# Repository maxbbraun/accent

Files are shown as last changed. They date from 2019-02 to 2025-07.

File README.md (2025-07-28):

# Accent

Accent is a smart picture frame with a pop of color and no cables. Read more about it [on Medium](https://accent.ink/info).

Accent (https://accent.ink)

## Client

The Accent client uses the [PlatformIO Arduino toolchain](https://platformio.org) for the [Waveshare ESP32 board](https://www.waveshare.com/wiki/E-Paper_ESP32_Driver_Board). See the [client control flow](client/README.md) for a high-level overview of the client code.

To push the client code to the board:
1. Configure the [IDE](https://platformio.org/platformio-ide) or [CLI](https://platformio.org/install/cli) with [`platformio.ini`](client/platformio.ini).
2. Pick one display type via `build_flags` in [`platformio.ini`](client/platformio.ini):
   - [GDEW075Z09](https://www.e-paper-display.com/products_detail/productId=324.html)  (7.5" 640x384 3-color)
   - [GDEW075Z08](https://www.e-paper-display.com/products_detail/productId=457.html) (7.5" 800x480 3-color)
   - [GDEH075Z90](https://www.good-display.com/product/344.html) (7.5" 880x528 3-color)
   - [GDEY1248Z51](https://www.good-display.com/product/422.html) (12.48" 1304x984 3-color, requires [DESPI-C1248](https://www.e-paper-display.com/products_detail/productId=418.html) adapter)
   - [GDEY073D46](https://www.good-display.com/product/442.html) (7.3" 800x480 7-color, comes with DESPI-C73 adapter)
3. If you want to point the client to a custom server, change `kBaseUrl` in [`Client.cpp`](client/src/Client.cpp).
4. Compile and upload with `pio run -t upload`.

Follow the on-screen instructions to connect the client to a Wifi access point. The settings will be preserved across uploads and can be reset manually. See the [setup documentation](https://accent.ink/setup) for details.

## Server

The Accent server is built on [Google App Engine](https://cloud.google.com/appengine/) using the [Python 3 runtime in the standard environment](https://cloud.google.com/appengine/docs/standard/python3/runtime). See the [server control flow](server/README.md) for a high-level overview of the server code.

The database backend uses [Cloud Firestore](https://firebase.google.com/products/firestore/). User-specific data is stored in the `users` collection with each user identified by a key generated by the client to identify it.
   - `/users/<USER_KEY>/home` - The home address used for the local time, the weather, and the commute origin.
   - `/users/<USER_KEY>/work` - The work address used for the commute destination.
   - `/users/<USER_KEY>/travel_mode` - The commute [travel mode](https://developers.google.com/maps/documentation/directions/intro#TravelModes).
   - `/users/<USER_KEY>/rotation` - The display rotation in degrees (0, 90, 180, or 270).
   - `/users/<USER_KEY>/schedule` - The content schedule.
   - `/users/<USER_KEY>/google_calendar_credentials` - The OAuth credentials for Google Calendar.

To populate the cross-user data after [setting up](https://firebase.google.com/docs/firestore/quickstart):
1. Obtain an API key for [Google Maps](https://cloud.google.com/maps-platform) and add it the `api_keys` collection under `/api_keys/google_maps/api_key`. Ensure that the [Maps Static API](https://console.cloud.google.com/apis/library/static-maps-backend.googleapis.com), [Directions API](https://console.cloud.google.com/apis/library/directions-backend.googleapis.com), [Geocoding API](https://console.cloud.google.com/apis/library/geocoding-backend.googleapis.com), [Maps Elevation API](https://console.cloud.google.com/apis/library/elevation-backend.googleapis.com), and [Time Zone API](https://console.cloud.google.com/apis/library/timezone-backend.googleapis.com) are all enabled and added to the key's restrictions. The [Cloud Vision API](https://console.cloud.google.com/apis/library/vision.googleapis.com) and [Google Calendar API](https://console.cloud.google.com/apis/library/calendar-json.googleapis.com) also need to be enabled, but they do not need a key.
2. Obtain an API key for [OpenWeather](https://openweathermap.org/guide) and add it in the `api_keys` collection under `/api_keys/open_weather/api_key`.
3. Obtain an [OAuth client ID](https://console.developers.google.com/apis/credentials) for the [Google Calendar API](https://developers.google.com/calendar/quickstart/python) with scope `https://www.googleapis.com/auth/calendar.readonly` in the OAuth consent screen. You will either need to make your OAuth app public or add your account to the list of test users. Configure the full `/oauth` URL of your App Engine app as an authorized redirect URI for the OAuth client. Write OAuth Client ID and Client Secret to the `client_id` and `client_secret` fields of the `google_calendar` document in the `oauth_clients` Firestore collection (`/oauth_clients/google_calendar`).

To test and deploy the server:
1. Install the [Google Cloud SDK](https://cloud.google.com/sdk/docs/), [create a project](https://cloud.google.com/resource-manager/docs/creating-managing-projects), and [authenticate with a service account](https://cloud.google.com/docs/authentication/getting-started).
2. Run `cd server && python3 -m venv venv && . venv/bin/activate`.
3. Run `pip install -r requirements.txt` (which also builds the [C extension](server/dithering_extension)).
4. Run the server locally with `export GOOGLE_CLOUD_PROJECT=$(gcloud config get-value project) && python main.py`.
5. Test the local server with:
   - [/hello/<USER_KEY>](http://localhost:8080/hello/<USER_KEY>) for the settings UI to edit user-specific data.
   - [/next?key=<USER_KEY>](http://localhost:8080/next?key=<USER_KEY>) for the time in milliseconds until the next schedule entry.
   - [/epd?key=<USER_KEY>](http://localhost:8080/epd?key=<USER_KEY>) for the currently scheduled client image used by the e-paper display.
   - [/gif?key=<USER_KEY>](http://localhost:8080/gif?key=<USER_KEY>) for a GIF version of the currently scheduled image for testing.
   - [/aicon?key=<USER_KEY>](http://localhost:8080/aicon?key=<USER_KEY>) to bypass the schedule and get the aicon image directly.
   - [/artwork?key=<USER_KEY>](http://localhost:8080/artwork?key=<USER_KEY>) to bypass the schedule and get the artwork image directly.
   - [/city?key=<USER_KEY>](http://localhost:8080/city?key=<USER_KEY>) to bypass the schedule and get the city image directly.
   - [/commute?key=<USER_KEY>](http://localhost:8080/commute?key=<USER_KEY>) to bypass the schedule and get the commute image directly.
   - [/calendar?key=<USER_KEY>](http://localhost:8080/calendar?key=<USER_KEY>) to bypass the schedule and get the calendar image directly.
   - [/everyone?key=<USER_KEY>](http://localhost:8080/everyone?key=<USER_KEY>) to bypass the schedule and get the everyone image directly.
   - [/wittgenstein?key=<USER_KEY>](http://localhost:8080/wittgenstein?key=<USER_KEY>) to bypass the schedule and get the wittgenstein image directly.
6. Deploy the server with `gcloud app deploy`.

## Frame

Files describing the Accent frame hardware include:
- A [Blender](https://www.blender.org/) project for simulating materials: [`frame.blend`](frame/frame.blend)
- A blueprint with basic dimensions: [`frame.pdf`](frame/frame.pdf)
- A [Shaper Origin](https://www.shapertools.com/) design: [`frame.svg`](frame/frame.svg)
- A [FreeCAD](https://www.freecadweb.org/) project: [`frame.FCStd`](frame/frame.FCStd)
- A G-code file for CNC milling: [`frame.gcode`](frame/frame.gcode)
- 3D models in STEP and STL formats: [`frame.step`](frame/frame.step) & [`frame.stl`](frame/frame.stl)

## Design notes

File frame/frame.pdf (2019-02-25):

1.00 mm

9.98 mm

3.02 mm

35.00 mm | 67.60 mm

123.63 mm

189.45 mm

170.20 mm

111.20 mm

97.63 mm

163.45 mm

3.38 mm

9.62 mm

1.00 mm

12.70 mm

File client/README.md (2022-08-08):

## Client

Entry point: [`Client.cpp`](src/Client.cpp)

### Regular Flow

```
┌────────────┐       ┌────────────┐       ┌────────────┐
│   Server   │       │   ESP32    │       │  Display   │
└─────┬──────┘       └─────┬──────┘       └─────┬──────┘
      │                    │                    │
      │                    ├───┐                │
      │                    │   │ Wake           │
      │                    │◀──┘                │
      │                    │                    │
      │                    ├───┐                │
      │                    │   │ Connect Wifi   │
      │                    │◀──┘                │
      │  /epd (Key, Size)  │                    │
    ┌─┤◀───────────────────┤                    │
    │ │                    │                    │
    │ │       Image        │                    │
    └─┼ ─ ─ ─ ─ ─ ─ ─ ─ ─ ▷│                    │
      │                    │    Show (Image)    │
      │                    ├───────────────────▶├─┐
      │                    │                    │ │
      │                    │                    │ │
      │                    │◁ ─ ─ ─ ─ ─ ─ ─ ─ ─ ┼─┘
      │    /next (Key)     │                    │
    ┌─┤◀───────────────────┤                    │
    │ │                    │                    │
    │ │     Sleep Time     │                    │
    └─┼ ─ ─ ─ ─ ─ ─ ─ ─ ─ ▷│                    │
      │                    │                    │
      │                    ├───┐                │
      │                    │   │ Sleep          │
      │                    │◀──┘                │
      │                    │                    │

```

### New Wifi Flow

```
┌────────────┐       ┌────────────┐       ┌────────────┐
│  Browser   │       │   ESP32    │       │  Display   │
└─────┬──────┘       └─────┬──────┘       └─────┬──────┘
      │                    │                    │
      │                    ├───┐                │
      │                    │   │ Wake           │
      │                    │◀──┘                │
      │                    │                    │
      │                    ├───┐                │
      │                    │   │ Connect Wifi   │
      │                    │x──┘                │
      │                    │                    │
      │                    │   Show (AP URL)    │
      │                    ├───────────────────▶├─┐
      │                    │                    │ │
      │                    │                    │ │
      │                    │◁ ─ ─ ─ ─ ─ ─ ─ ─ ─ ┼─┘
      │                    │                    │
      │                    ├───┐                │
      │                    │   │ Start AP       │
      │  AP URL            │◀──┘                │
    ┌─┤◀────────○          │                    │
    │ │                    │                    │
    │ │  Wifi Credentials  │                    │
    └─┤─ ─ ─ ─ ─ ─ ─ ─ ─ ─▷│                    │
      │                    │                    │
      │                    ├───┐                │
      │                    │   │ Restart        │
      │                    │◀──┘                │
      │                    │                    │
   ┌──┴────────────────────┴────────────────────┴──┐
   │                                               │
   │                 Regular Flow                  │
   │                                               │
   └──┬────────────────────┬────────────────────┬──┘
      │                    │                    │
```

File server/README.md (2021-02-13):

## Server

Entry point: [`main.py`](main.py)

### Regular Flow

```
┌────────────┐       ┌────────────┐       ┌────────────┐
│   Client   │       │ App Engine │       │ Firestore  │
└─────┬──────┘       └─────┬──────┘       └─────┬──────┘
      │                    │                    │
      ├───┐                │                    │
      │   │ Wake           │                    │
      │◀──┘                │                    │
      │                    │                    │
      │  /epd (Key, Size)  │                    │
      ├───────────────────▶├─┐ Schedule (User)  │
      │                    │ ├─────────────────▶├─┐
      │                    │ │                  │ │
      │                    │ │    User Data     │ │
      │   Content Image    │ │◁ ─ ─ ─ ─ ─ ─ ─ ─ ┼─┘
      │◁ ─ ─ ─ ─ ─ ─ ─ ─ ─ ┼─┘                  │
      │                    │                    │
      ├───┐                │                    │
      │   │ Display        │                    │
      │◀──┘                │                    │
      │                    │                    │
      │    /next (Key)     │                    │
      ├───────────────────▶├─┐ Schedule (User)  │
      │                    │ ├─────────────────▶├─┐
      │                    │ │                  │ │
      │                    │ │    User Data     │ │
      │     Sleep Time     │ │◁ ─ ─ ─ ─ ─ ─ ─ ─ ┼─┘
      │◁ ─ ─ ─ ─ ─ ─ ─ ─ ─ ┼─┘                  │
      │                    │                    │
      ├───┐                │                    │
      │   │ Sleep          │                    │
      │◀──┘                │                    │
      │                    │                    │
```

### New User Flow

```
┌────────────┐       ┌────────────┐       ┌────────────┐       ┌────────────┐
│   Client   │       │ App Engine │       │ Firestore  │       │  Browser   │
└─────┬──────┘       └─────┬──────┘       └─────┬──────┘       └─────┬──────┘
      │                    │                    │                    │
      ├───┐                │                    │                    │
      │   │ Wake           │                    │                    │
      │◀──┘                │                    │                    │
      │                    │                    │                    │
      │  /epd (Key, Size)  ├─┐ Schedule (User)  │                    │
      ├───────────────────▶│ ├─────────────────▶├─┐                  │
      │                    │ │                  │ │                  │
      │                    │ │      Error       │ │                  │
      │ Settings URL Image │ │x ─ ─ ─ ─ ─ ─ ─ ─ ┼─┘                  │
      │◁ ─ ─ ─ ─ ─ ─ ─ ─ ─ ┼─┘                  │                    │
      │                    │                    │                    │
      ├───┐                │                    │                    │
      │   │ Display        │                    │                    │
      │◀──┘                │                    │       Settings URL │
      │                    │                    │     ○─────────────▶├─┐
      ├───┐                │                    │                    │ │
      │   │ Sleep          │                    │     User Data      │ │
      │◀──┘                │                    │◁ ─ ─ ─ ─ ─ ─ ─ ─ ─ ┼─┘
      │                    │                    │                    │
   ┌──┴────────────────────┴────────────────────┴────────────────────┴──┐
   │                                                                    │
   │                            Regular Flow                            │
   │                                                                    │
   └──┬────────────────────┬────────────────────┬────────────────────┬──┘
      │                    │                    │                    │
```

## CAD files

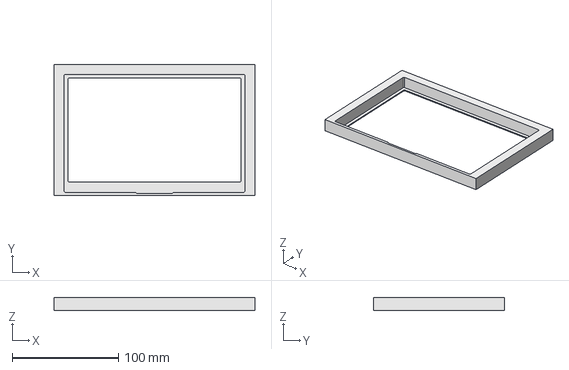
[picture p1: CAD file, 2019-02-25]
frame/frame.step
189.4 x 123.6 x 12.7 mm

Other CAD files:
frame/frame.FCStd
frame/frame.blend
frame/frame.stl

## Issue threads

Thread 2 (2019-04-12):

Red color and voltage

maxbbraun, 2019-04-12:
Sometimes, when using 3.7V battery power, the red pixels are not bright enough. This does not happen with 5V USB power.

There may be a different way to [initialize](https://github.com/maxbbraun/accent/blob/master/client/display.h#L89) or [refresh](https://github.com/maxbbraun/accent/blob/master/client/display.h#L158) the display which avoids this issue.

maxbbraun, 2021-02-16:
9868d1da35801458c72f2fb4c08cf8ae0a589f81 and using the [GDEW075Z08](https://www.e-paper-display.com/products_detail/productId=457.html) (800x480) display seems to fix this.

Closed 2021-02-16.

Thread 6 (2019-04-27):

Client interface for Wifi setup

maxbbraun, 2019-04-27:
1. At first boot, create an [access point](https://github.com/espressif/arduino-esp32/blob/master/libraries/WiFi/examples/WiFiAccessPoint/WiFiAccessPoint.ino) with a [static IP](https://github.com/espressif/arduino-esp32/blob/master/libraries/WiFi/src/WiFiAP.cpp#L147)
2. Show an image with instructions to connect to the AP and open a browser to the IP address
3. [Serve](https://github.com/espressif/arduino-esp32/blob/master/libraries/WebServer/examples/HelloServer/HelloServer.ino) a small website with a form for SSID and password
4. Handle the form request by saving SSID and password to [NVS](https://docs.espressif.com/projects/esp-idf/en/latest/api-reference/storage/nvs_flash.html)
5. Use the saved credentials when [connecting to Wifi](https://github.com/maxbbraun/accent/blob/master/client/client.ino#L61)
6. If connecting to Wifi fails or times out, go back to 1

maxbbraun, 2019-05-04:
Some remaining work:
- Make web server use https
- Respond with confirmation after saving form and restarting

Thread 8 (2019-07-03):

Not all map copyright text is properly replaced

maxbbraun, 2019-07-03:
Failure case example:

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

maxbbraun, 2019-07-03:
Better:

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

Closed 2019-07-03.

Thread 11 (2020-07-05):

Dark Sky API no longer accepting signups

KianYeo, 2020-07-05:
Hi,

The Dark Sky API is no longer accepting signups. Are there any other alternatives or what modifications can be made to the server code to disable the dark sky api call?

maxbbraun, 2020-07-05:
Switched to the [AccuWeather API](https://developer.accuweather.com) in 1c4fe954a23f8fa932ececf023520b2baddb0d99.

Closed 2020-07-05.

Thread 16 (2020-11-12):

Setting Up Client

energysteward, 2020-11-12:
I'm trying to follow these instructions from your ReadMe.

To push the client code to the board:

Add your server base URL to Client.ino.
Use the board information in Client.ino to set up the environment.
Verify and upload the sketch.
Finally, follow the on-screen instructions to connect the client to a Wifi access point.

Honestly, I've never worked with Arduino devices. I followed the instructions but nothing is appearing on the e-ink screen. These are instructions are too "calm" for me.

I verified, compiled and uploaded the client.ino file with no errors, but nothing is occuring. The e-ink screen is blank white.

What am I missing?

maxbbraun, 2020-11-16:
Could you paste the serial output from the client here?

NeilBetham, 2021-04-09:
I seem to be running into a similar issue with a recent ESP32 e-Paper dev board from Waveshare. Oddly enough after flashing the board the first stage bootloader fires up but the main app fails almost immediately after that. Somewhat surprising there isn't a stack trace getting printed.

```
ets Jun  8 2016 00:22:57

rst:0x1 (POWERON_RESET),boot:0x13 (SPI_FAST_FLASH_BOOT)
configsip: 0, SPIWP:0xee
clk_drv:0x00,q_drv:0x00,d_drv:0x00,cs0_drv:0x00,hd_drv:0x00,wp_drv:0x00
mode:DIO, clock div:1
load:0x3fff0018,len:4
load:0x3fff001c,len:1216
ho 0 tail 12 room 4
load:0x40078000,len:10944
load:0x40080400,len:6388
entry 0x400806b4
\xFFNo
```

Still trying to figure out the cause. I have a logic analyzer attached to the UART of the ESP32 and it looks like after printing the `No` text it's either resetting or something is getting corrupted which cause it to start dumping garbage to the UART. You can see that the baud rate changes significantly after the `o` is sent:
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

I'll update once I know some more about what's happening.

NeilBetham, 2021-04-09:
Okay, update. It looks like there is an issue with the arduino-esp32 compatibility layer. After digging through the GX_EPD lib there is a second call to `Serial.begin` which is causing the issue. By setting the serial baud rate to 0 in the `gx_epd->init` call inside Display.h the issue is mitigated and I can now see the AccentSetup screen when the esp32 boots. Not optimal as you no longer get debug messages from the display library but will get the display lib up and running in the short term.

maxbbraun, 2021-04-09:
Hm, I'm not able to reproduce the issue. For me, the second call to `Serial.begin` works and I get messages from both the Accent code and the GxEPD library. Is this a first run thing for you or does it still happen if you set the baud rate back to normal after the device is fully set up?

NeilBetham, 2021-04-09:
So the first `Serial.begin` in Client.ino is fine; it's whenever someone calls it again that becomes the issue. For some reason it corrupts the serial interface. I can try removing that and then letting GxEPD do the init to see if that mitigates the issue or not. Out of curiosity, what core version are you running in the arduino IDE? The version I have installed is 1.0.6.

NeilBetham, 2021-04-09:
So if I let GxEPD call `Serial.begin` I can also get the debug messages from there as well. Though I do miss the couple messages that get printed from Client.ino / Network before GxEPD init's the UART. Suffice it to say I don't think this is a bug in the Accent client just an issue in the underlying arduino-esp32 layer.

maxbbraun, 2021-04-09:
Oh, I see. I'm using Arduino IDE 1.8.13 and esp32 version 1.0.2.

NeilBetham, 2021-04-09:
Okay, confirmed the issue is in the arduino-esp32 cores somewhere after 1.0.2. I downgraded to the 1.0.2 rev and I don't experience the same hanging issue as with 1.0.6. Though calling `Serial.begin` again does appear to nuke the buffers as I miss out on most of the messages that happen between startup and GxEPD init.

maxbbraun, 2021-04-09:
I was also able to reproduce with esp32>=1.0.5 while 1.0.4 still seems to work fine.

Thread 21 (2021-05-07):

Connecting a LiPo battery to Waveshare e-Paper ESP32 board

knyar, 2021-05-07:
Hi @maxbbraun, thanks a lot for sharing the details about this project. I have a hardware-related question, I hope it's OK to ask it here.

In your [medium post](https://onezero.medium.com/meet-accent-352cfa95813a) you mentined that you connected the board to a 3.7v LiPo battery. I noticed that the board only has 5v and 3.3v pins, while LiPo batteries produce 4.2v while fully charged.

Did you use a voltage regulator while connecting the battery to the 3.3v pin, or does the board work fine with the battery connected directly to the 3.3v (or 5v)? Thanks!

maxbbraun, 2021-05-08:
I directly connected it to the 3.3V pin. Not the cleanest solution, but it worked.

knyar, 2021-05-08:
Thanks! I will try connecting directly as well.

Closed 2021-05-08.

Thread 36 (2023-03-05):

Internal Server Error when setting up new device

maxbbraun, 2023-03-05:
```
 Traceback (most recent call last):
  File "/layers/google.python.pip/pip/lib/python3.9/site-packages/flask/app.py", line 2077, in wsgi_app
    response = self.full_dispatch_request()
  File "/layers/google.python.pip/pip/lib/python3.9/site-packages/flask/app.py", line 1525, in full_dispatch_request
    rv = self.handle_user_exception(e)
  File "/layers/google.python.pip/pip/lib/python3.9/site-packages/flask/app.py", line 1523, in full_dispatch_request
    rv = self.dispatch_request()
  File "/layers/google.python.pip/pip/lib/python3.9/site-packages/flask/app.py", line 1509, in dispatch_request
    return self.ensure_sync(self.view_functions[rule.endpoint])(**req.view_args)
  File "/srv/auth.py", line 90, in wrapper
    return settings_response(key, image_response, width,
  File "/srv/response.py", line 90, in settings_response
    return image_func(image)
TypeError: epd_response() missing 1 required positional argument: 'variant'
```

Closed 2023-03-05.

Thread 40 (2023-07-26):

Internal Server Error on /hello/<USER_KEY>

bdaneshgar, 2023-07-26:
I am thinking out loud. I get a server error when testing  `/hello/<USER_KEY>`

My calendar is probably set up incorrectly:
- I have only filled `oath_client/google_calendar `document with the `client_id` and `client_secret`
- I have not filled out the `/users/<USER_KEY>/google_calendar_credentials`
- Is `/users/<USER_KEY>/google_calendar_credentials` to be set up in the `/hello/<USER_KEY>` page.

Any insight into helping me get into thepage is much appreciated!

> [/hello/<USER_KEY>](http://localhost:8080/hello/%3CUSER_KEY%3E) for the settings UI to edit user-specific data.

Internal Server Error

> [/next?key=<USER_KEY>](http://localhost:8080/next?key=%3CUSER_KEY%3E) for the time in milliseconds until the next schedule entry.

This works

> [/epd?key=<USER_KEY>](http://localhost:8080/epd?key=%3CUSER_KEY%3E) for the currently scheduled client image used by the e-paper display.

This downloads serial gibberish

> [/gif?key=<USER_KEY>](http://localhost:8080/gif?key=%3CUSER_KEY%3E) for a GIF version of the currently scheduled image for testing.

this triggers the `settings_response` function in `response.py`

> [/artwork?key=<USER_KEY>](http://localhost:8080/artwork?key=%3CUSER_KEY%3E) to bypass the schedule and get the artwork image directly.

This works

> [/city?key=<USER_KEY>](http://localhost:8080/city?key=%3CUSER_KEY%3E) to bypass the schedule and get the city image directly.

This works

> [/commute?key=<USER_KEY>](http://localhost:8080/commute?key=%3CUSER_KEY%3E) to bypass the schedule and get the commute image directly.

This works

> [/calendar?key=<USER_KEY>](http://localhost:8080/calendar?key=%3CUSER_KEY%3E) to bypass the schedule and get the calendar image directly.

Internal Server Error

> [/everyone?key=<USER_KEY>](http://localhost:8080/everyone?key=%3CUSER_KEY%3E) to bypass the schedule and get the everyone image directly.

I am everyone

> [/wittgenstein?key=<USER_KEY>](http://localhost:8080/wittgenstein?key=%3CUSER_KEY%3E) to bypass the schedule and get the wittgenstein image directly.

This works.

bdaneshgar, 2023-07-26:
I did notice that my browser autocorrected to `oath_clients`. I noticed in the `README.md`, there is a reference to both `oauth_client` and `oauth_clients` and I see that only `oauth_clients` is valid.

I am still having trouble with my `/calendar?key=<USER_KEY>` and `/hello/<USER_KEY>`

bdaneshgar, 2023-07-26:
I took out extraneous URIs from my OAuth Client and it now works!

maxbbraun, 2023-07-28:
Thanks for catching the typo!

Closed 2023-07-26.

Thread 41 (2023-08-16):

Client only retrieves certain images

bdaneshgar, 2023-08-16:
Client will display pages `calendar`, `artwork`, `wittgenstein`, and `city`, but fails to show content and displays a `settings_response` for `commute` and `everyone`. Any idea how this could be happening? The server is creating the image just fine.

bdaneshgar, 2023-10-31:
I am using my own server. Here is the terminal from the client:

```Updating display
_PowerOn : 134997
Busy Timeout!
_Update_Full : 20001053
_PowerOff : 157000
Read 768 bytes (96000 total)
Download complete
Suspending display
_PowerOff : 40000
Scheduling sleep
Requesting URL: https://accent-393823.wl.r.appspot.com/next
Status code: 200
Sleep server response: 24262361
Sleeping for 24262361000 us

maxbbraun, 2023-11-02:
Do you see any error logs on the server? This client log looks fine, but it also only shows the request and response for `/next` and not for `/epd`, which should be just before it. If both are status `200`, then I'd expect the error to be server-side.

bdaneshgar, 2023-11-02:
I'm getting the following. I'm using a waveshare 7.5", 800x480 display:

```{
  "textPayload": "ERROR:root:Failed to create Schedule content: Requested a 800x480 map but got 640x480. Try this: https://developers.google.com/maps/documentation/maps-static/start#Largerimagesizes",
  "insertId": "6543d721000194d63da926f1",
  "resource": {
    "type": "gae_app",
    "labels": {
      "module_id": "default",
      "version_id": "20230726t204946",
      "zone": "us-west2-2",
      "project_id": "accent-393823"
    }
  },
  "timestamp": "2023-11-02T17:06:41.103638Z",
  "labels": {
    "clone_id": "0037d6d5d376b858968d6299719bd5842919fa4263d2ece4aa0be475e49ef2a3c70944e8a7c7ff3634e0728b8a85f50fef53971b9523afd72475b084676cf6908f"
  },
  "logName": "projects/accent-393823/logs/stderr",
  "receiveTimestamp": "2023-11-02T17:06:41.356828278Z"
}
```

```
{
  "textPayload": "Traceback (most recent call last):\n  File \"/srv/commute.py\", line 59, in image\n    image = self._google_maps.map_image(width, height, variant,\n  File \"/srv/google_maps.py\", line 154, in map_image\n    raise DataError('Requested a %dx%d map but got %dx%d. Try this: ht'\nfirestore.DataError: Requested a 800x480 map but got 640x480. Try this: https://developers.google.com/maps/documentation/maps-static/start#Largerimagesizes",
  "insertId": "6543d721000194f0f6995feb",
  "resource": {
    "type": "gae_app",
    "labels": {
      "zone": "us-west2-2",
      "version_id": "20230726t204946",
      "module_id": "default",
      "project_id": "accent-393823"
    }
  },
  "timestamp": "2023-11-02T17:06:41.103664Z",
  "severity": "ERROR",
  "labels": {
    "clone_id": "0037d6d5d376b858968d6299719bd5842919fa4263d2ece4aa0be475e49ef2a3c70944e8a7c7ff3634e0728b8a85f50fef53971b9523afd72475b084676cf6908f"
  },
  "logName": "projects/accent-393823/logs/stderr",
  "receiveTimestamp": "2023-11-02T17:06:41.356828278Z",
  "errorGroups": [
    {
      "id": "CM-fi8rVrO2PBQ"
    }
  ]
}
```

```
{
  "textPayload": "During handling of the above exception, another exception occurred:",
  "insertId": "6543d721000194f91d0612de",
  "resource": {
    "type": "gae_app",
    "labels": {
      "zone": "us-west2-2",
      "module_id": "default",
      "version_id": "20230726t204946",
      "project_id": "accent-393823"
    }
  },
  "timestamp": "2023-11-02T17:06:41.103673Z",
  "labels": {
    "clone_id": "0037d6d5d376b858968d6299719bd5842919fa4263d2ece4aa0be475e49ef2a3c70944e8a7c7ff3634e0728b8a85f50fef53971b9523afd72475b084676cf6908f"
  },
  "logName": "projects/accent-393823/logs/stderr",
  "receiveTimestamp": "2023-11-02T17:06:41.356828278Z"
}
```

```
{
  "textPayload": "Traceback (most recent call last):\n  File \"/srv/response.py\", line 96, in content_response\n    image = content.image(user, width, height, variant)\n  File \"/srv/schedule.py\", line 142, in image\n    image = self._image(latest_entry['image'], user, width, height,\n  File \"/srv/schedule.py\", line 110, in _image\n    return content.image(user, width, height, variant)\n  File \"/srv/commute.py\", line 62, in image\n    raise ContentError(e)\ncontent.ContentError: Requested a 800x480 map but got 640x480. Try this: https://developers.google.com/maps/documentation/maps-static/start#Largerimagesizes",
  "insertId": "6543d7210001950594c4c255",
  "resource": {
    "type": "gae_app",
    "labels": {
      "project_id": "accent-393823",
      "zone": "us-west2-2",
      "module_id": "default",
      "version_id": "20230726t204946"
    }
  },
  "timestamp": "2023-11-02T17:06:41.103685Z",
  "severity": "ERROR",
  "labels": {
    "clone_id": "0037d6d5d376b858968d6299719bd5842919fa4263d2ece4aa0be475e49ef2a3c70944e8a7c7ff3634e0728b8a85f50fef53971b9523afd72475b084676cf6908f"
  },
  "logName": "projects/accent-393823/logs/stderr",
  "receiveTimestamp": "2023-11-02T17:06:41.356828278Z",
  "errorGroups": [
    {
      "id": "COiBvcjWneT1kgE"
    }
  ]
}
```

maxbbraun, 2023-11-03:
The first error message explains what's going on:

> Failed to create Schedule content: Requested a 800x480 map but got 640x480. Try this: https://developers.google.com/maps/documentation/maps-static/start#Largerimagesizes

You can follow the link for more info and ways to fix it.

bdaneshgar, 2023-11-06:
Unfortunately, I got this response from Google Cloud Support:

> Hi,Unfortunately your request has been rejected by the engineering team since it is for personal use and low usage , please use the default maximum imagery size. if your usage increases you can try to apply again later.

 Additionally, `epd.py` has default display sizes set to 640x384. I am having trouble finding out how the larger sizes are being requested in the first place.

i will try to dig deeper and report back. In the meantime, if you are able to figure out how to lower the size of the request (or give me guidance as to how many requests I would need to satisfy Google), I would appreciate the help.

maxbbraun, 2023-11-07:
> Additionally, `epd.py` has default display sizes set to 640x384. I am having trouble finding out how the larger sizes are being requested in the first place.

The default values for the display size (and variant) are only used when the request doesn't specify any size. See [here](https://github.com/maxbbraun/accent/blob/e4d07de050256f6b0b3db25046bc9116bffa265d/server/response.py#L108). This is mainly a fallback for compatibility with older clients. So in your case, the client is requesting an 800x480 image. If your display is 640x384 instead, you should change the client configuration [here](https://github.com/maxbbraun/accent/blob/e4d07de050256f6b0b3db25046bc9116bffa265d/client/platformio.ini#L19).

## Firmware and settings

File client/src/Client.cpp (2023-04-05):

#include <Arduino.h>
#include "Display.h"
#include "Network.h"
#include "Power.h"

// The baud rate for the serial connection.
const uint32_t kSerialSpeed = 115200;

// The GPIO pin used to reset Wifi settings.
const uint8_t kWifiResetPin = 23;

// The base URL for server requests.
const String kBaseUrl = "https://accent.ink";

// The URL for the next wake time endpoint.
const String kNextEndpoint = kBaseUrl + "/next";

// The URL for the e-paper display image endpoint.
const String kEpdEndpoint = kBaseUrl + "/epd";

// The size in bytes of the streaming HTTP response and image buffers.
const uint32_t kStreamBufferSize = 1024;

// The time in milliseconds to wait before restarting after an error.
uint64_t kRestartDelayMs = 60 * 60 * 1000;  // 1 hour

// Helper library instances.
Display display(kSerialSpeed);
Network network(kSerialSpeed);
Power power;

// Streams the image from the server and sends it to the display in chunks.
bool downloadImage() {
  Serial.println("Downloading image");
  HTTPClient http;

  // Request the current image from the server.
  if (!network.HttpGet(&http, kEpdEndpoint,
                       {"width", String(display.Width()),
                        "height", String(display.Height()),
                        "variant", display.Variant()})) {
    return false;
  }

  // Start reading from the stream.
  uint8_t buffer[kStreamBufferSize];
  WiFiClient* stream = http.getStreamPtr();
  uint32_t total_count = 0;
  do {
    if (!http.connected()) {
      Serial.println("Connection lost");
      http.end();
      return false;
    }

    Serial.printf("%d bytes available\n", stream->available());

    // Fill the buffer.
    uint32_t count = stream->readBytes(buffer, sizeof(buffer));

    // Send the buffer to the display.
    display.Load(buffer, count, total_count);

    total_count += count;
    Serial.printf("Read %lu bytes (%lu total)\n", count, total_count);
  } while (stream->available() > 0);

  Serial.println("Download complete");
  http.end();
  return true;
}

// Sleeps for a time received from the server.
void scheduleSleep() {
  Serial.println("Scheduling sleep");
  HTTPClient http;

  // Request the next wake time from the server.
  if (!network.HttpGet(&http, kNextEndpoint)) {
    return;
  }

  // Read the sleep time from the server.
  String delay_ms_str = http.getString();
  http.end();
  Serial.printf("Sleep server response: %s\n", delay_ms_str.c_str());
  uint64_t delay_ms = strtoull(delay_ms_str.c_str(), nullptr, 10);
  power.DeepSleep(delay_ms);
}

void setup() {
  Serial.begin(kSerialSpeed);

  // Check if the Wifi reset pin has been connected to GND.
  pinMode(kWifiResetPin, INPUT_PULLUP);
  delay(1);  // Wait for pull-up to become active.
  if (digitalRead(kWifiResetPin) == LOW) {
    network.ResetWifi();
  }

  // Connect to Wifi or start the setup flow.
  if (!network.ConnectWifi()) {
    display.ShowWifiSetup();
    network.StartWifiSetupServer();
    return;
  }

  // Show the latest image.
  display.Initialize();
  if (!downloadImage()) {
    return;
  }
  display.Finalize();

  // Go to sleep until the next refresh.
  scheduleSleep();
}

void loop() {
  if (network.HandleWifiSetupServer()) {
    // Continue to loop.
    return;
  }

  // Falling through means there was an error.
  Serial.println("Restarting after error");
  display.ShowError();
  power.DeepSleep(kRestartDelayMs);
}

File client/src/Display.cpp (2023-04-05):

#include "Display.h"

// Waveshare ESP32 SPI pin assignments.
const int8_t kSpiPinMiso = 12;
const int8_t kSpiPinSck = 13;
const int8_t kSpiPinMosi = 14;
const int8_t kSpiPinCs = 15;
const int8_t kSpiPinBusy = 25;
const int8_t kSpiPinRst = 26;
const int8_t kSpiPinDc = 27;

// Display color variant identifiers for the server request.
const String kVariant7Color = "7color";
const String kVariant3Color = "bwr";

void Display::Initialize() {
  Serial.println("Initializing display");

  // Allocate display buffers.
  gx_epd_ = new GFX_CLASS<DISPLAY_TYPE, PAGE_HEIGHT>(
#ifdef DISPLAY_GDEY1248Z51
      // Configure the DESPI-C1248 connection board for this display type.
      GxEPD2_1248c(kSpiPinSck, kSpiPinMiso, kSpiPinMosi, /* CS M1 */ 23,
                   /* CS S1 */ 22, /* CS M2 */ 16, /* CS S2 */ 19,
                   /* DC 1 */ 25, /* DC 2 */ 17, /* RST 1 */ 33, /* RST 2 */ 5,
                   /* BUSY M1 */ 32, /* BUSY S1 */ 26, /* BUSY M2 */ 18,
                   /* BUSY S2 */ 4)
#else
      // Use the standard Waveshare configuration for all other display types.
      DISPLAY_TYPE(kSpiPinCs, kSpiPinDc, kSpiPinRst, kSpiPinBusy)
#endif
  );
  gx_epd_->init(serial_speed_);

  // Remap the Waveshare ESP32's non-standard SPI pins.
  SPI.end();
  SPI.begin(kSpiPinSck, kSpiPinMiso, kSpiPinMosi, kSpiPinCs);

  // Start paged drawing.
  gx_epd_->firstPage();
}

void Display::Load(const uint8_t* image_data, uint32_t size, uint32_t offset) {
  Serial.printf("Loading image data: %lu bytes\n", size);

  // The number of pixels per input byte depends on the display variant.
  const uint8_t pixels_per_byte = (Variant() == kVariant7Color ? 2 : 4);

  // Look at the image data one byte at a time.
  for (int i = 0; i < size; ++i) {
    // Convert the input byte to display pixels.
    uint8_t input = image_data[i];
    uint16_t pixels[pixels_per_byte];
    if (Variant() == kVariant7Color) {
      // Read 2 4-bit input pixels per byte.
      pixels[0] = ConvertPixel(input, 0xF0, 4);
      pixels[1] = ConvertPixel(input, 0x0F, 0);
    } else {  // Variant() == kVariant3Color
      // Read 4 2-bit input pixels per byte.
      pixels[0] = ConvertPixel(input, 0xC0, 6);
      pixels[1] = ConvertPixel(input, 0x30, 4);
      pixels[2] = ConvertPixel(input, 0x0C, 2);
      pixels[3] = ConvertPixel(input, 0x03, 0);
    }

    // Write the output pixels.
    for (int in = 0; in < pixels_per_byte; ++in) {
      uint16_t pixel = pixels[in];
      uint32_t out = pixels_per_byte * (offset + i) + in;
      int16_t x = out % gx_epd_->width();
      int16_t y = out / gx_epd_->width();
      gx_epd_->drawPixel(x, y, pixel);

      // Trigger a display update after the last pixel of each page.
      if ((y + 1) % gx_epd_->pageHeight() == 0 && x == gx_epd_->width() - 1) {
        Serial.println("Updating display");
        gx_epd_->nextPage();
      }
    }
  }
}

void Display::Finalize() {
  Serial.println("Suspending display");
  gx_epd_->hibernate();

  // Free display buffers.
  delete gx_epd_;
}

void Display::ShowError() {
  ShowStatic(kErrorImageBlack, kErrorImageRed, kErrorWidth, kErrorHeight,
             kErrorBackground);
}

void Display::ShowWifiSetup() {
  ShowStatic(kWifiImageBlack, kWifiImageRed, kWifiWidth, kWifiHeight,
             kWifiBackground);
}

int16_t Display::Width() { return gx_epd_->width(); }

int16_t Display::Height() { return gx_epd_->height(); }

String Display::Variant() { return VARIANT; }

uint16_t Display::ConvertPixel(uint8_t input, uint8_t mask, uint8_t shift) {
  // Isolate the relevant bits from the input.
  uint8_t value = (input & mask) >> shift;

  // Convert the input value to a display color.
  if (Variant() == kVariant7Color) {
    switch (value) {
      case 0x0:
        return GxEPD_BLACK;
      case 0x1:
        return GxEPD_WHITE;
      case 0x2:
        return GxEPD_GREEN;
      case 0x3:
        return GxEPD_BLUE;
      case 0x4:
        return GxEPD_RED;
      case 0x5:
        return GxEPD_YELLOW;
      case 0x6:
        return GxEPD_ORANGE;
      default:
        Serial.printf("Unknown 7-color value: 0x%02X\n", value);
        return GxEPD_BLACK;
    }
  } else {  // Variant() == kVariant3Color
    switch (value) {
      case 0x0:
        return GxEPD_BLACK;
      case 0x1:
        return GxEPD_WHITE;
      case 0x3:
        return GxEPD_RED;
      default:
        Serial.printf("Unknown 3-color value: 0x%02X\n", value);
        return GxEPD_BLACK;
    }
  }
}

void Display::ShowStatic(const uint8_t* black_data, const uint8_t* red_data,
                         uint16_t width, uint16_t height, uint16_t background) {
  Serial.println("Showing static image");

  Initialize();

  // Calculate the offset to center the static image in the display.
  int16_t x = (gx_epd_->width() - width) / 2;
  int16_t y = (gx_epd_->height() - height) / 2;

  do {
    // Fill in the background first.
    gx_epd_->fillScreen(background);

    // Draw the static image one color at a time.
    gx_epd_->fillRect(x, y, width, height, GxEPD_WHITE);
    gx_epd_->drawBitmap(x, y, black_data, width, height, GxEPD_BLACK);
    gx_epd_->drawBitmap(x, y, red_data, width, height, GxEPD_RED);
  } while (gx_epd_->nextPage());

  Finalize();
}

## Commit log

2019-02-25 Add the hardware files
    [frame.FCStd, frame.step, frame.stl]
2019-02-25 Remove local file path from STEP file
    [frame.step]
2019-03-03 Switch to pixel assets for the calendar
    - Replace font with number bitmaps.
    - Bake binarization into image assets.
2019-03-14 Some commute UI fixes
    - Use the current timestamp to get live traffic
    - Correctly color transit lines and stations
2019-04-07 Update city texture
    [frame.blend]
2019-04-07 Add more animation frames and stronger ease in/out
    [frame.blend]
2019-04-13 Use the current weather instead of daily
2019-04-27 Basic user authentication
    - The client generates unique key (currently MAC address) and sends a basic access authentication header
    - The server uses a Cloud Firestore database for user-specific data (time zone, home, work, travel mode, schedule) based on client key
    - The server also uses the database for cross-user data (API keys)
    - For unknown users the image response points to a new user flow (not implemented yet)
    - Renamed g_calendar.py to google_calendar.py
    - Renamed now.py to local_time.py
    - Reduced weather cache timeout from 1 hour to 5 minutes
    - Refactored response helpers into response.py
    - Fixed typos
2019-04-29 Avoid error screen during new user flow
    Return a fixed retry delay instead of a forbidden status. Part of issue #3.
2019-05-01 Settings UI improvements
    - Add preview buttons for each schedule entry
    - Open app permissions in new window
2019-05-03 Remove deep sleep workaround
    [Client.ino]
2019-05-04 Implement Wifi setup (issue #6)
    [Client.ino, Display.cpp, Display.h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]
2019-05-08 Downgrade user not found error to warning
    Part of regular new user flow
2019-05-09 Show error if image request fails
    [Client.ino]
2019-05-13 More granular error handling
    - Use DataError to group root causes
    - Use ContentError to aggregate and redirect to settings flow
2019-05-18 Add sequence diagrams for client and server flows
    Made with https://monodraw.helftone.com
2019-05-25 Make Google Calendar auth flow more robust
    - Delete any credentials determined to be invalid
    - No resubmit form warning on settings page anymore
    - Move more OAuth flow logic out of main
2020-07-05 Switch to the AccuWeather API
    Dark Sky is deprecated: https://blog.darksky.net
2020-07-07 Switch to the OpenWeather API
    Its free tier is more generous than AccuWeather
2021-02-04 Mark the current time in the settings timeline
2021-02-13 Migrate client to the GxEPD2 library
    https://github.com/ZinggJM/GxEPD2
    - Remove custom SPI code
    - Support multiple display types
    - Request display resolution from server
    - Generate static images for multiple displays
    - Update READMEs
2021-06-26 Fix occasional Wifi setup server issues
    Workaround from https://github.com/espressif/arduino-esp32/issues/985
    [Network.cpp]
2025-07-28 Remove person generation and safety filter settings from image generation config
2025-07-28 Switch to Vertex AI auth for image generation
2025-07-28 Add explicit safety filter settings
